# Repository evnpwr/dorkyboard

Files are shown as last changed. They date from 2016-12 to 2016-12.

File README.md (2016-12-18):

Dorkyboard
===========
Dorkyboard is a 104-key keyboard with an ISO-style enter key and backslash key, and an otherwise ANSI-like layout. It has a number pad. I know number pads aren't cool, but hey, I'm a dork.
The dorkyboard is in its very early stages. The hardware is completely untested (boards are not yet manufactured) and the firmware is non-existant.
Dorkyboard uses Cherry MX switches. The mechanical design of the Dorkyboard is extrememly minimal. There is no enclosure. The keys are not mounted on a plate. They mount directly to the PCB. The PCB sits on adhesive rubber feet. There are lots and lots of rubber feet to minimize board flex. 
The microcontroller is an Atmel ATMEGA32U4, the same microcontroller used in the Arduino Micro.The microcontroller's supporting circuitry is based on the Arduino Micro.
The Cherry MX PCB footprints are slightly modified versions of the footprints created by Fredrik Atmer of BathroomEpiphanies. The original footprints are available here: https://github.com/BathroomEpiphanies/KiCAD-Keyboard-Tutorial  
Thank you, Mr. Atmer.  
Dorkyboard is an open hardware project. It is licensed under the CERN OHL v1.2. It is designed using KiCad.

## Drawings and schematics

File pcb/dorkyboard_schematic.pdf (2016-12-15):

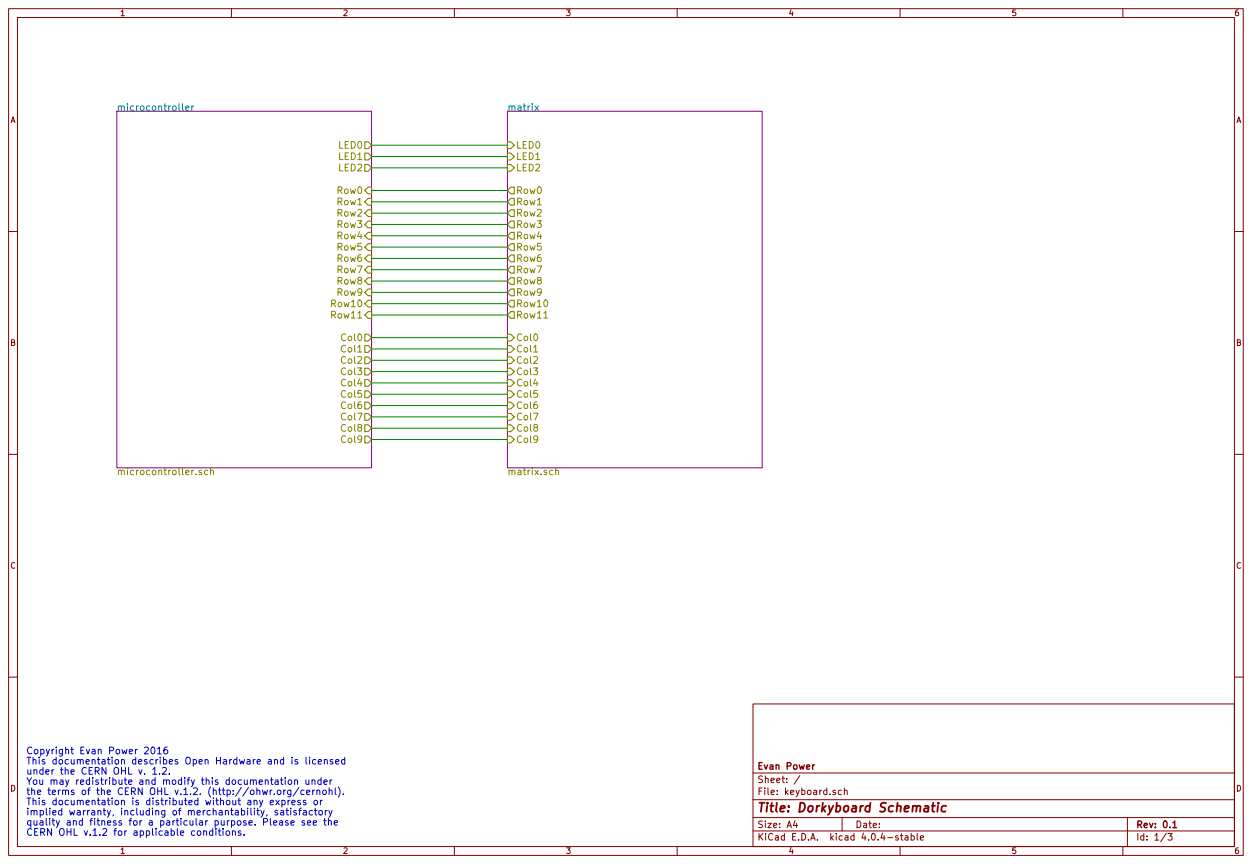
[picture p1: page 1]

This documentation describes Open Hardware and is licensed
under the CERN OHL v. 1.2.
You may redistribute and modify this documentation under
the terms of the CERN OHL v.1.2. (http://ohwr.org/cernohl).
This documentation is distributed without any express or
implied warranty, including of merchantability, satisfactory
quality and fitness for a particular purpose. Please see the
CERN OHL v.1.2 for applicable conditions.

File: keyboard.sch Sheet: / Evan Power

Id: 1/3 Title: Dorkyboard Schematic

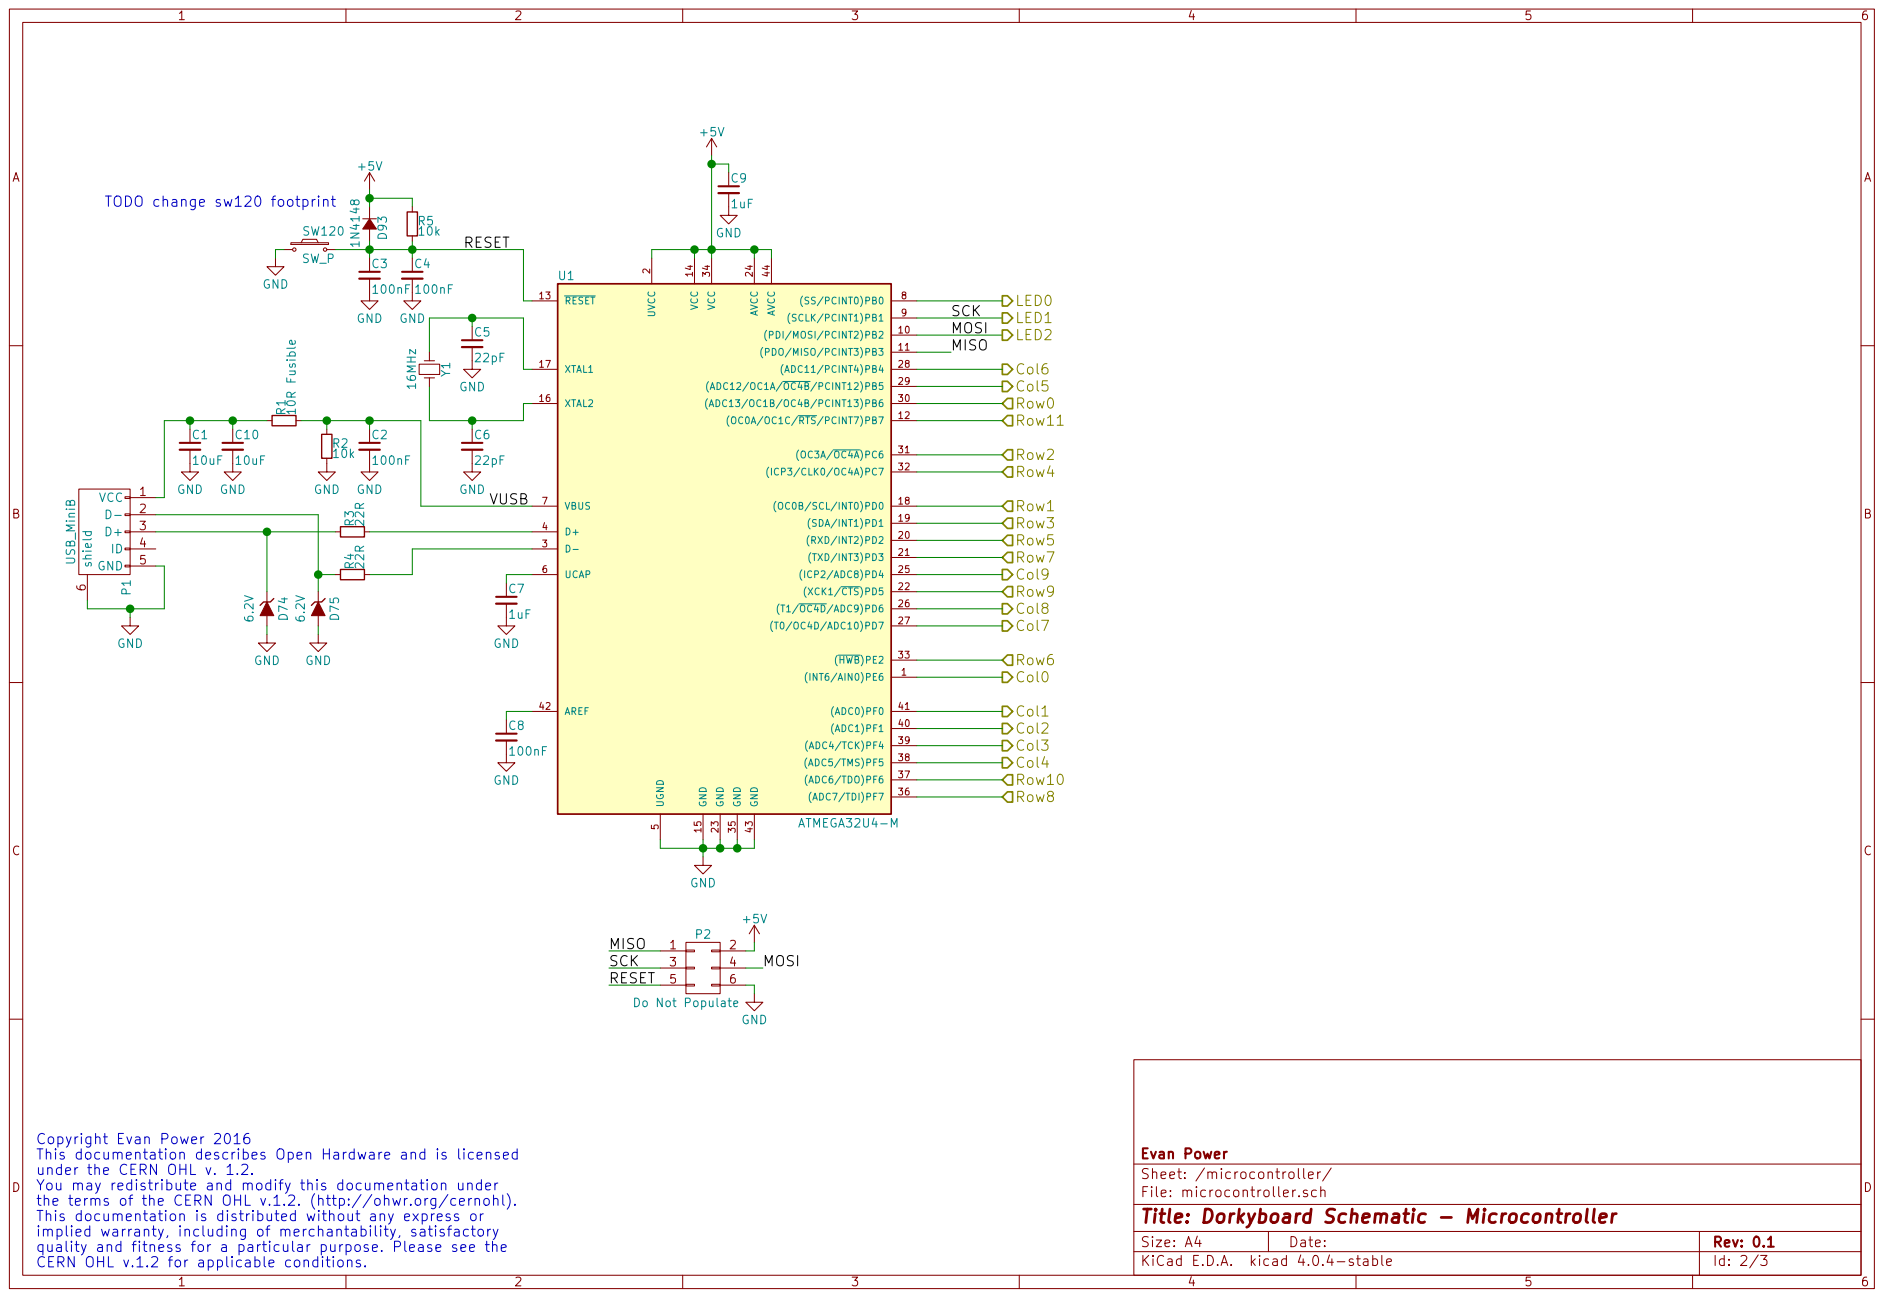
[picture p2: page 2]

6P1 USB_MiniB R322R 6.2V D74 GND GND R110R Fusible GND

Copyright Evan Power 2016
This documentation describes Open Hardware and is licensed
under the CERN OHL v. 1.2.
You may redistribute and modify this documentation under
the terms of the CERN OHL v.1.2. (http://ohwr.org/cernohl).
This documentation is distributed without any express or
implied warranty, including of merchantability, satisfactory
CERN OHL v.1.2 for applicable conditions.

Id: 2/3 Title: Dorkyboard Schematic - Microcontroller File: microcontroller.sch Sheet: /microcontroller/ Evan Power

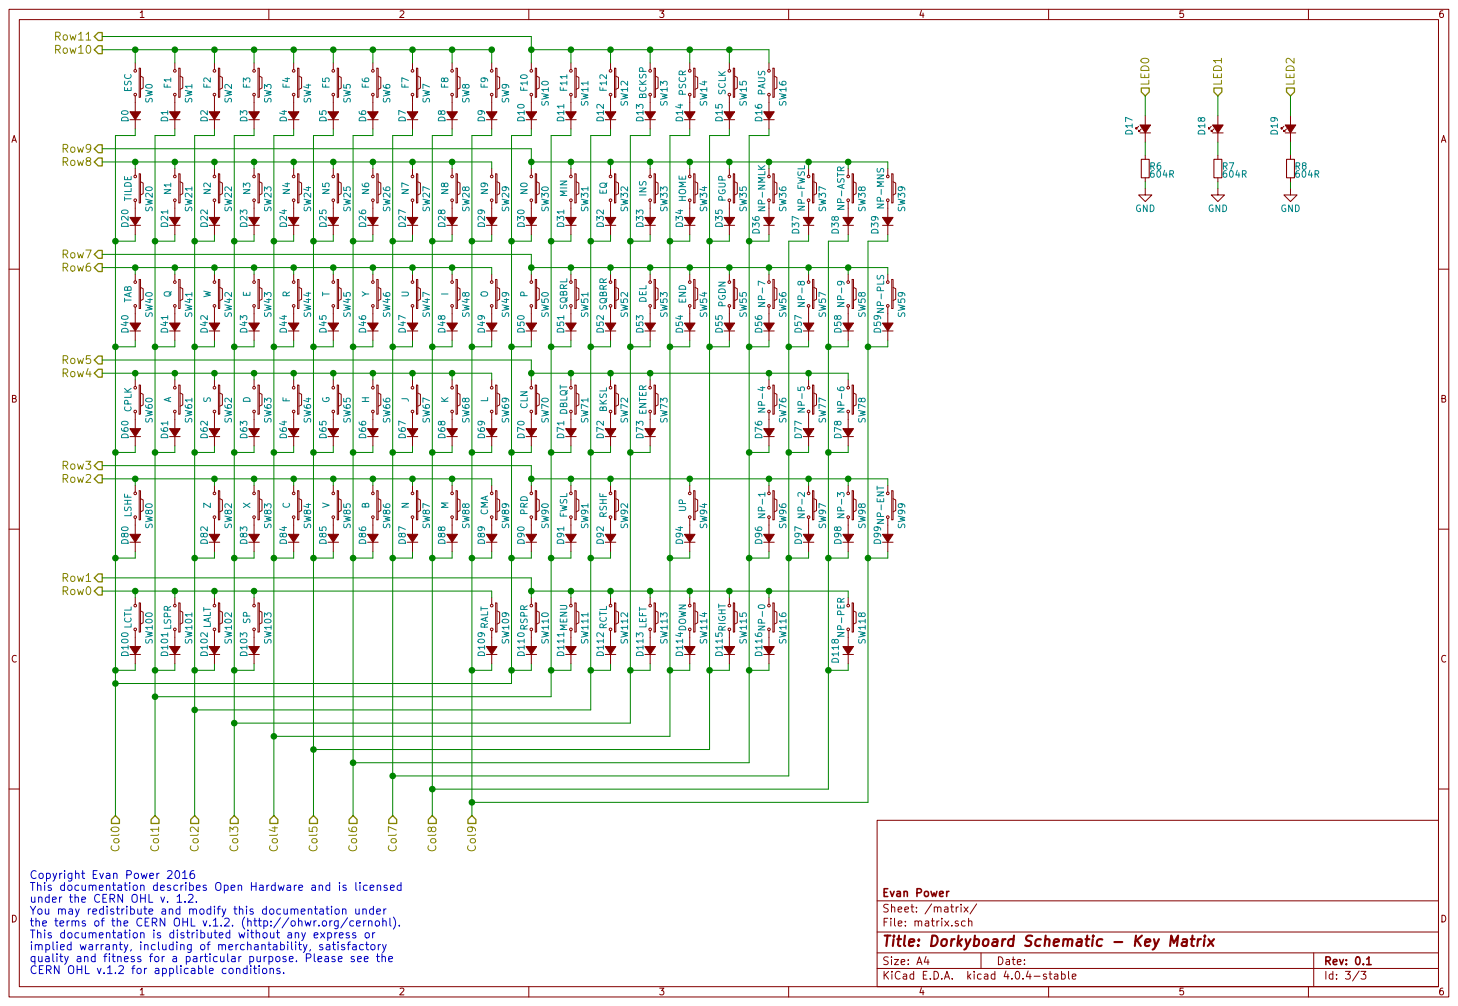
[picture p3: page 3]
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

Id: 3/3 Title: Dorkyboard Schematic - Key Matrix

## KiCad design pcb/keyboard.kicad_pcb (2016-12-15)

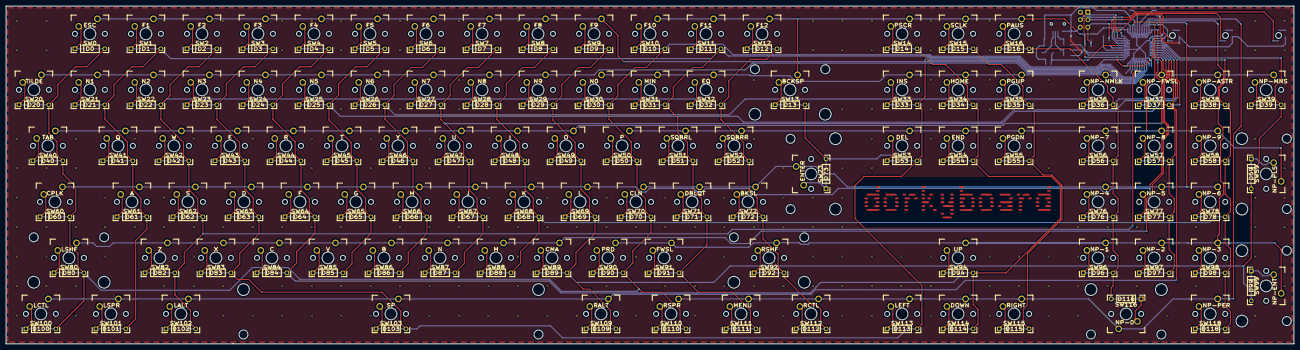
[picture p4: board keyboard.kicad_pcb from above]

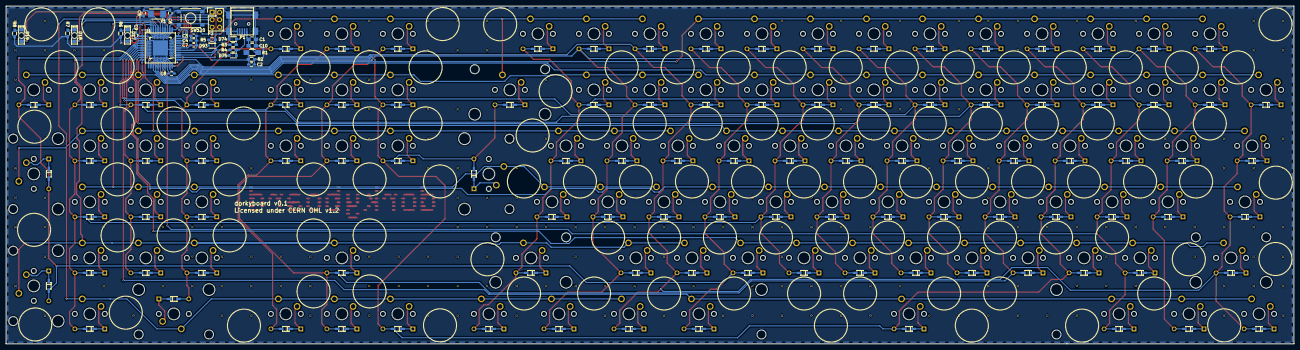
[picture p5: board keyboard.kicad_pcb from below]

Board: 2 copper layers, 436.8 x 114.6 mm, 237 parts (29 on the bottom side), 146 nets.

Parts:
C1, C10: 10uF; C_0805_HandSoldering
C2, C3, C4, C8: 100nF; C_0603_HandSoldering
C5, C6: 22pF; C_0603_HandSoldering
C7, C9: 1uF; C_0603_HandSoldering
D0, D1, D2, D3, D4, D5, D6, D7, D8, D9, D10, D11, D12, D13, D14, D15, D16, D20, D21, D22, D23, D24, D25, D26, D27, D28, D29, D30, D31, D32, D33, D34, D35, D36, D37, D38, D39, D40, D41, D42, D43, D44, D45, D46, D47, D48, D49, D50, D51, D52, D53, D54, D55, D56, D57, D58, D59, D60, D61, D62, D63, D64, D65, D66, D67, D68, D69, D70, D71, D72, D73, D76, D77, D78, D80, D82, D83, D84, D85, D86, D87, D88, D89, D90, D91, D92, D94, D96, D97, D98, D99, D100, D101, D102, D103, D109, D110, D111, D112, D113, D114, D115, D116, D118: D_Small; DIODE_TH-SMT
D17, D18, D19: Led_Small; LED Reverse Mount 3.2x1.6mm Dialight
D74, D75: 6.2V; SOD-323_HandSoldering
D93: 1N4148; SOD-323
P1: USB_MiniB; USB_Mini-B
P2: Do Not Populate; Pin_Header_Straight_2x03
R1: 10R Fusible; R_1206_HandSoldering
R2, R5: 10k; R_0603_HandSoldering
R3, R4: 22R; R_0603_HandSoldering
R6, R7, R8: 604R; R_0603_HandSoldering
SW0: ESC; CHERRY_PCB_100H
SW1: F1; CHERRY_PCB_100H
SW2: F2; CHERRY_PCB_100H
SW3: F3; CHERRY_PCB_100H
SW4: F4; CHERRY_PCB_100H
SW5: F5; CHERRY_PCB_100H
SW6: F6; CHERRY_PCB_100H
SW7: F7; CHERRY_PCB_100H
SW8: F8; CHERRY_PCB_100H
SW9: F9; CHERRY_PCB_100H
SW10: F10; CHERRY_PCB_100H
SW11: F11; CHERRY_PCB_100H
SW12: F12; CHERRY_PCB_100H
SW13: BCKSP; CHERRY_PCB_200H
SW14: PSCR; CHERRY_PCB_100H
SW15: SCLK; CHERRY_PCB_100H
SW16: PAUS; CHERRY_PCB_100H
SW20: TILDE; CHERRY_PCB_100H
SW21: N1; CHERRY_PCB_100H
SW22: N2; CHERRY_PCB_100H
SW23: N3; CHERRY_PCB_100H
SW24: N4; CHERRY_PCB_100H
SW25: N5; CHERRY_PCB_100H
SW26: N6; CHERRY_PCB_100H
SW27: N7; CHERRY_PCB_100H
SW28: N8; CHERRY_PCB_100H
SW29: N9; CHERRY_PCB_100H
SW30: N0; CHERRY_PCB_100H
SW31: MIN; CHERRY_PCB_100H
SW32: EQ; CHERRY_PCB_100H
SW33: INS; CHERRY_PCB_100H
SW34: HOME; CHERRY_PCB_100H
SW35: PGUP; CHERRY_PCB_100H
SW36: NP-NMLK; CHERRY_PCB_100H
SW37: NP-FWSL; CHERRY_PCB_100H
SW38: NP-ASTR; CHERRY_PCB_100H
SW39: NP-MNS; CHERRY_PCB_100H
SW40: TAB; CHERRY_PCB_150H
SW41: Q; CHERRY_PCB_100H
SW42: W; CHERRY_PCB_100H
SW43: E; CHERRY_PCB_100H
SW44: R; CHERRY_PCB_100H
SW45: T; CHERRY_PCB_100H
SW46: Y; CHERRY_PCB_100H
SW47: U; CHERRY_PCB_100H
SW48: I; CHERRY_PCB_100H
SW49: O; CHERRY_PCB_100H
SW50: P; CHERRY_PCB_100H
SW51: SQBRL; CHERRY_PCB_100H
SW52: SQBRR; CHERRY_PCB_100H
SW53: DEL; CHERRY_PCB_100H
SW54: END; CHERRY_PCB_100H
SW55: PGDN; CHERRY_PCB_100H
SW56: NP-7; CHERRY_PCB_100H
SW57: NP-8; CHERRY_PCB_100H
SW58: NP-9; CHERRY_PCB_100H
SW59: NP-PLS; CHERRY_PCB_200V
SW60: CPLK; CHERRY_PCB_175H
SW61: A; CHERRY_PCB_100H
SW62: S; CHERRY_PCB_100H
SW63: D; CHERRY_PCB_100H
SW64: F; CHERRY_PCB_100H
SW65: G; CHERRY_PCB_100H
SW66: H; CHERRY_PCB_100H
SW67: J; CHERRY_PCB_100H
SW68: K; CHERRY_PCB_100H
SW69: L; CHERRY_PCB_100H
SW70: CLN; CHERRY_PCB_100H
SW71: DBLQT; CHERRY_PCB_100H
SW72: BKSL; CHERRY_PCB_100H
SW73: ENTER; CHERRY_PCB_ISOR
SW76: NP-4; CHERRY_PCB_100H
SW77: NP-5; CHERRY_PCB_100H
SW78: NP-6; CHERRY_PCB_100H
SW80: LSHF; CHERRY_PCB_225H
SW82: Z; CHERRY_PCB_100H
SW83: X; CHERRY_PCB_100H
SW84: C; CHERRY_PCB_100H
SW85: V; CHERRY_PCB_100H
SW86: B; CHERRY_PCB_100H
SW87: N; CHERRY_PCB_100H
SW88: M; CHERRY_PCB_100H
SW89: CMA; CHERRY_PCB_100H
SW90: PRD; CHERRY_PCB_100H
SW91: FWSL; CHERRY_PCB_100H
SW92: RSHF; CHERRY_PCB_275H
SW94: UP; CHERRY_PCB_100H
SW96: NP-1; CHERRY_PCB_100H
SW97: NP-2; CHERRY_PCB_100H
SW98: NP-3; CHERRY_PCB_100H
SW99: NP-ENT; CHERRY_PCB_200V
SW100: LCTL; CHERRY_PCB_125H
SW101: LSPR; CHERRY_PCB_125H
SW102: LALT; CHERRY_PCB_125H
SW103: SP; CHERRY_PCB_625H
SW109: RALT; CHERRY_PCB_125H
SW110: RSPR; CHERRY_PCB_125H
SW111: MENU; CHERRY_PCB_125H
SW112: RCTL; CHERRY_PCB_125H
SW113: LEFT; CHERRY_PCB_100H
SW114: DOWN; CHERRY_PCB_100H
SW115: RIGHT; CHERRY_PCB_100H
SW116: NP-0; CHERRY_PCB_200H
SW118: NP-PER; CHERRY_PCB_100H
SW120: SW_P; SW_SPST_PTS645
U1: ATMEGA32U4-M; QFN44-7x7mm-QFP-10x10mm
Y1: 16MHz; Crystal_SMD_5032_2Pads

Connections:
+5V: C9.1, D93.1, P2.2, R5.1, U1.2, U1.14, U1.24, U1.34, U1.44
/matrix/Col0: D0.1, D10.1, D20.1, D30.1, D40.1, D50.1, D60.1, D70.1, D80.1, D90.1, D100.1, D110.1, U1.1
/matrix/Col1: D1.1, D11.1, D21.1, D31.1, D41.1, D51.1, D61.1, D71.1, D91.1, D101.1, D111.1, U1.41
/matrix/Col2: D2.1, D12.1, D22.1, D32.1, D42.1, D52.1, D62.1, D72.1, D82.1, D92.1, D102.1, D112.1, U1.40
/matrix/Col3: D3.1, D13.1, D23.1, D33.1, D43.1, D53.1, D63.1, D73.1, D83.1, D103.1, D113.1, U1.39
/matrix/Col4: D4.1, D14.1, D24.1, D34.1, D44.1, D54.1, D64.1, D84.1, D94.1, D114.1, U1.38
/matrix/Col5: D5.1, D15.1, D25.1, D35.1, D45.1, D55.1, D65.1, D85.1, D115.1, U1.29
/matrix/Col6: D6.1, D16.1, D26.1, D36.1, D46.1, D56.1, D66.1, D76.1, D86.1, D96.1, D116.1, U1.28
/matrix/Col7: D7.1, D27.1, D37.1, D47.1, D57.1, D67.1, D77.1, D87.1, D97.1, U1.27
/matrix/Col8: D8.1, D28.1, D38.1, D48.1, D58.1, D68.1, D78.1, D88.1, D98.1, D118.1, U1.26
/matrix/Col9: D9.1, D29.1, D39.1, D49.1, D59.1, D69.1, D89.1, D99.1, D109.1, U1.25
/matrix/LED0: D17.2, U1.8
/matrix/LED1: D18.2, P2.3, U1.9
/matrix/LED2: D19.2, P2.4, U1.10
/matrix/Row0: SW100.1, SW101.1, SW102.1, SW103.1, SW109.1, U1.30
/matrix/Row1: SW110.1, SW111.1, SW112.1, SW113.1, SW114.1, SW115.1, SW116.1, SW118.1, U1.18
/matrix/Row2: SW80.1, SW82.1, SW83.1, SW84.1, SW85.1, SW86.1, SW87.1, SW88.1, SW89.1, U1.31
/matrix/Row3: SW90.1, SW91.1, SW92.1, SW94.1, SW96.1, SW97.1, SW98.1, SW99.1, U1.19
/matrix/Row4: SW60.1, SW61.1, SW62.1, SW63.1, SW64.1, SW65.1, SW66.1, SW67.1, SW68.1, SW69.1, U1.32
/matrix/Row5: SW70.1, SW71.1, SW72.1, SW73.1, SW76.1, SW77.1, SW78.1, U1.20
/matrix/Row6: SW40.1, SW41.1, SW42.1, SW43.1, SW44.1, SW45.1, SW46.1, SW47.1, SW48.1, SW49.1, U1.33
/matrix/Row7: SW50.1, SW51.1, SW52.1, SW53.1, SW54.1, SW55.1, SW56.1, SW57.1, SW58.1, SW59.1, U1.21
/matrix/Row8: SW20.1, SW21.1, SW22.1, SW23.1, SW24.1, SW25.1, SW26.1, SW27.1, SW28.1, SW29.1, U1.36
/matrix/Row9: SW30.1, SW31.1, SW32.1, SW33.1, SW34.1, SW35.1, SW36.1, SW37.1, SW38.1, SW39.1, U1.22
/matrix/Row10: SW0.1, SW1.1, SW2.1, SW3.1, SW4.1, SW5.1, SW6.1, SW7.1, SW8.1, SW9.1, U1.37
/matrix/Row11: SW10.1, SW11.1, SW12.1, SW13.1, SW14.1, SW15.1, SW16.1, U1.12
/microcontroller/MISO: P2.1, U1.11
/microcontroller/RESET: C3.1, C4.1, D93.2, P2.5, R5.2, SW120.2, U1.13
/microcontroller/VUSB: C2.1, R1.2, R2.1, U1.7
GND: C1.2, C2.2, C3.2, C4.2, C5.2, C6.2, C7.2, C8.2, C9.2, C10.2, D74.2, D75.2, P1.5, P1.6, P2.6, R2.2, R6.2, R7.2, R8.2, SW120.1, U1.5, U1.15, U1.23, U1.35, U1.43, U1.45
unnamed: C1.1, C10.1, P1.1, R1.1
unnamed: C5.1, U1.17, Y1.1
unnamed: C6.1, U1.16, Y1.2
unnamed: C7.1, U1.6
unnamed: C8.1, U1.42
unnamed: D0.2, SW0.2
unnamed: D1.2, SW1.2
unnamed: D2.2, SW2.2
unnamed: D3.2, SW3.2
unnamed: D4.2, SW4.2
unnamed: D5.2, SW5.2
unnamed: D6.2, SW6.2
unnamed: D7.2, SW7.2
unnamed: D8.2, SW8.2
unnamed: D9.2, SW9.2
unnamed: D10.2, SW10.2
unnamed: D11.2, SW11.2
unnamed: D12.2, SW12.2
unnamed: D13.2, SW13.2
unnamed: D14.2, SW14.2
unnamed: D15.2, SW15.2
unnamed: D16.2, SW16.2
unnamed: D17.1, R6.1
unnamed: D18.1, R7.1
unnamed: D19.1, R8.1
unnamed: D20.2, SW20.2
unnamed: D21.2, SW21.2
unnamed: D22.2, SW22.2
unnamed: D23.2, SW23.2
unnamed: D24.2, SW24.2
unnamed: D25.2, SW25.2
unnamed: D26.2, SW26.2
unnamed: D27.2, SW27.2
unnamed: D28.2, SW28.2
unnamed: D29.2, SW29.2
unnamed: D30.2, SW30.2
unnamed: D31.2, SW31.2
unnamed: D32.2, SW32.2
unnamed: D33.2, SW33.2
unnamed: D34.2, SW34.2
unnamed: D35.2, SW35.2
unnamed: D36.2, SW36.2
unnamed: D37.2, SW37.2
unnamed: D38.2, SW38.2
unnamed: D39.2, SW39.2
unnamed: D40.2, SW40.2
unnamed: D41.2, SW41.2
unnamed: D42.2, SW42.2
unnamed: D43.2, SW43.2
unnamed: D44.2, SW44.2
unnamed: D45.2, SW45.2
unnamed: D46.2, SW46.2
unnamed: D47.2, SW47.2
unnamed: D48.2, SW48.2
unnamed: D49.2, SW49.2
unnamed: D50.2, SW50.2
unnamed: D51.2, SW51.2
unnamed: D52.2, SW52.2
unnamed: D53.2, SW53.2
unnamed: D54.2, SW54.2
unnamed: D55.2, SW55.2
unnamed: D56.2, SW56.2
unnamed: D57.2, SW57.2
unnamed: D58.2, SW58.2
unnamed: D59.2, SW59.2
unnamed: D60.2, SW60.2
unnamed: D61.2, SW61.2
unnamed: D62.2, SW62.2
unnamed: D63.2, SW63.2
unnamed: D64.2, SW64.2
unnamed: D65.2, SW65.2
unnamed: D66.2, SW66.2
unnamed: D67.2, SW67.2
unnamed: D68.2, SW68.2
unnamed: D69.2, SW69.2
unnamed: D70.2, SW70.2
unnamed: D71.2, SW71.2
unnamed: D72.2, SW72.2
unnamed: D73.2, SW73.2
unnamed: D74.1, P1.3, R3.1
unnamed: D75.1, P1.2, R4.1
unnamed: D76.2, SW76.2
unnamed: D77.2, SW77.2
unnamed: D78.2, SW78.2
unnamed: D80.2, SW80.2
unnamed: D82.2, SW82.2
unnamed: D83.2, SW83.2
unnamed: D84.2, SW84.2
unnamed: D85.2, SW85.2
unnamed: D86.2, SW86.2
unnamed: D87.2, SW87.2
unnamed: D88.2, SW88.2
unnamed: D89.2, SW89.2
unnamed: D90.2, SW90.2
unnamed: D91.2, SW91.2
unnamed: D92.2, SW92.2
unnamed: D94.2, SW94.2
unnamed: D96.2, SW96.2
unnamed: D97.2, SW97.2
unnamed: D98.2, SW98.2
unnamed: D99.2, SW99.2
unnamed: D100.2, SW100.2
unnamed: D101.2, SW101.2
unnamed: D102.2, SW102.2
unnamed: D103.2, SW103.2
unnamed: D109.2, SW109.2
unnamed: D110.2, SW110.2
unnamed: D111.2, SW111.2
unnamed: D112.2, SW112.2
unnamed: D113.2, SW113.2
unnamed: D114.2, SW114.2
unnamed: D115.2, SW115.2
unnamed: D116.2, SW116.2
unnamed: D118.2, SW118.2
unnamed: R3.2, U1.4
unnamed: R4.2, U1.3

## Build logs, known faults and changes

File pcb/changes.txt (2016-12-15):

Changes
=======

Version 0.1
  December 2016
  Initial version

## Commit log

2016-12-12 new file: pcb/keyboard.kicad_pcb new file: pcb/keyboard.pro new file: pcb/keyboard.sch new file: pcb/matrix.sch new file: pcb/microcontroller.sch new file: pcb/placeDiodes.py
    [keyboard.kicad_pcb, keyboard.sch, matrix.sch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]
2016-12-12 new file: pcb/LedReverseMount3_2x1_6mmDialight.pretty/LED Reverse Mount 3.2x1.6mm Dialight.kicad_mod new file: pcb/QFN44-7x7mm-QFP-10x10mm.pretty/QFN44-7x7mm-QFP-10x10mm.kicad_mod new file: pcb/pcbLo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
2016-12-15 modified: ../README.md modified: LedReverseMount3_2x1_6mmDialight.pretty/LED Reverse Mount 3.2x1.6mm Dialight.kicad_mod new file: cern_ohl_v_1_2.txt new file: cern_ohl_v_1_2_howto.pdf new file: chang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
    [dorkeyboard-B.Cu.gbr, dorkeyboard-B.Mask.gbr, dorkeyboard-B.SilkS.gbr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]

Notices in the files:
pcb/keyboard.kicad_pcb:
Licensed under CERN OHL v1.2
